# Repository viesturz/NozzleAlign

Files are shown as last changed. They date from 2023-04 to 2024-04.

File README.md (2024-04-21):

# NozzleAlign Probe
A mechanical nozzle probe to align multiple tools. And Nozzle probe offset.
Repeatable to ~0.01 mm.

| **[Ball probe](./BallProbe.md)** | **[Low profile ball proble](./LowProfileBallProbe.md)** | **[Rail probe](./RailProbe.md)** |
| --- | --- | --- |
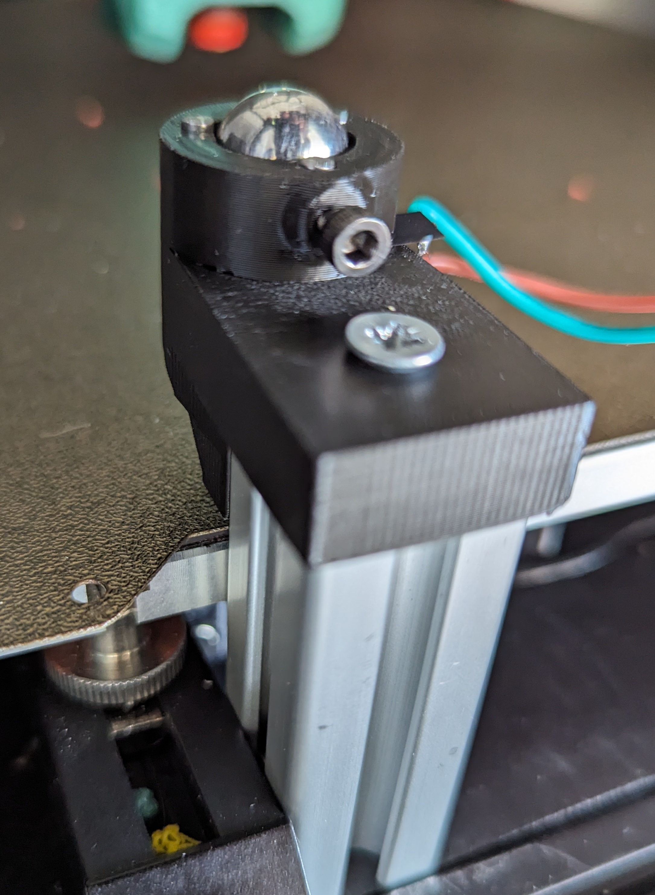
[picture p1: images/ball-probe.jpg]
Ball probe
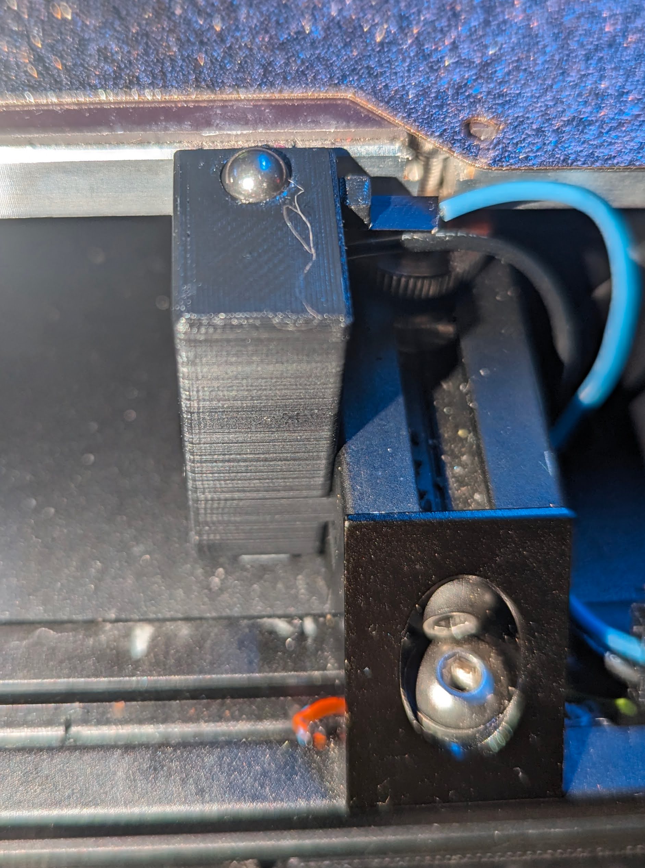
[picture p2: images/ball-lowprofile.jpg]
Low profile Ball probe
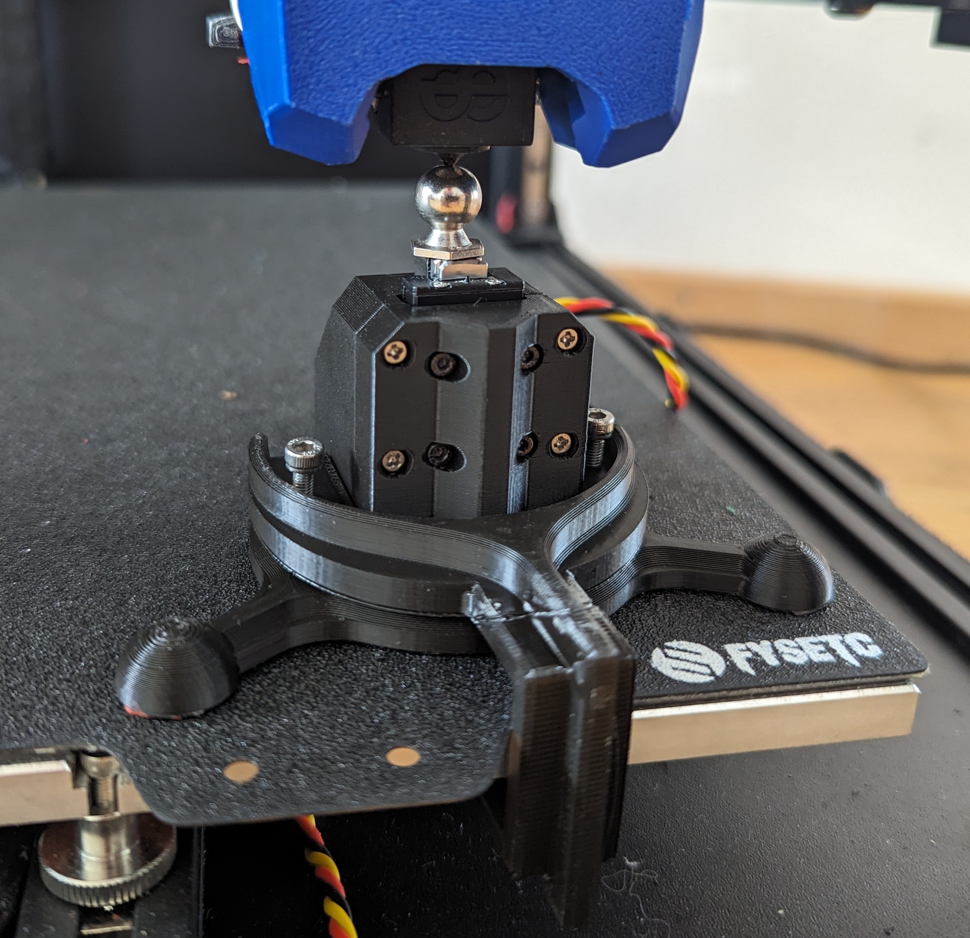
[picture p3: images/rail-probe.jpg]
Ball probe
|  |  |  |

## Klipper integration

### Installing

Install the [klipper-toolchanger](https://github.com/viesturz/klipper-toolchanger) extension.

### Configuration

See the macros folder for an example.

```
[tools_calibrate]
pin: ^!PF5
travel_speed: 20  # mms to travel sideways for XY probing
spread: 7  # mms to travel down from top for XY probing
lower_z: 1.0  # The speed (in mm/sec) to move tools down onto the probe
speed: 2  # The speed (in mm/sec) to retract between probes
lift_speed: 4  # Z Lift after probing done, should be greater than any Z variance between tools
final_lift_z: 6 
sample_retract_dist:2
samples_tolerance:0.05
samples:5
samples_result: median # median, average

# Settings for nozzle probe calibration - optional.
probe: probe # name of the nozzle probe to use

trigger_to_bottom_z: 0.25 # Offset from probe trigger to vertical motion bottoms out. 
# decrease if the nozzle is too high, increase if too low.
```

### Clean your nozzles 

The calibration accuracy is as good as your nozzles are clean. 
Clean all nozzles throughly before calibrating.

### Calibrating tool offsets

- First position the nozzle approximately above the probe - the probe will find the center on it's own within 1-2 mm.

- The first tool has all offsets to 0 and is used as a baseline for other tools. Run ```TOOL_LOCATE_SENSOR``` to calibrate nozzle location for tool 0.

- For every other tool, run ```TOOL_CALIBRATE_TOOL_OFFSET``` to measure the offset from the first tool.

All probing moves and final offsets will be printed in the console.

### Calibrating nozzle bed probe.

- Do the first two steps from above to ensure the probe is precisely under the nozzle.

- Run TOOL_CALIBRATE_PROBE_OFFSET - to measure Z offset from nozzle triggering the probe to tool's nozzle probe activating.

All probing moves and final offsets will be printed in the console.

## Troubleshooting

- **Probe triggered prior to movement**, the nozzle is not touching the probe
  - Check if the probe is triggering without touching - use a multimiter to check for continuity and if it changes when pressing down on the probe.
  - Check if the pin is configured correctly. The example configuration is for active low with a pullup. Depending how you have wired it, you might need remove the **^!** for active-high.
- **Probe triggered prior to movement**, the nozzle is touching the probe, could have probed a few times already
  - Likely the initial position was too far off-center. Try to position it more accurately.
  - The probe is lowered too much and/or not enough sideways - tweak ```lower_z``` and ```spread```

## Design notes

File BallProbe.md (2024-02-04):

# Ball probe

A rigidly mountable nozzle calibration probe using bearing balls. Accuracy is no worse than the linear rail probe.

Two versions for 12.7mm and 10mm balls available.

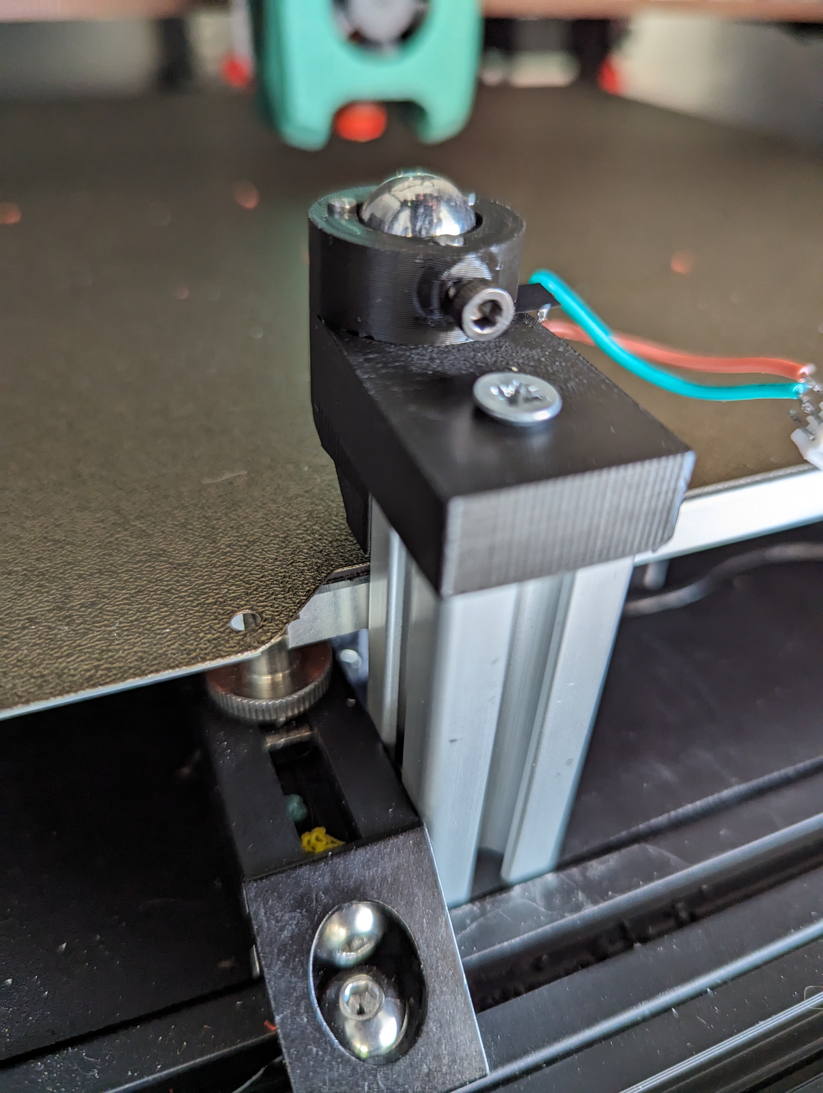
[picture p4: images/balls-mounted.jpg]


## BOM
* 2x steel ball, 10.0 or 12.7 mm
* a ~20mm piece of 0.1mmx6mm springsteel, ripped mine out of 1m tape measure.
* 3x 9mm x 3mm steel rod
* 1x 6mm x 3mm screw for adjustment
* 60mm 2020 extrusion for mounting.
* mounting hardware to attach it to your printer.
* some ~1000 grit sandpaper.

## Assembly

- Clean up the springsteel insertion slot, it should go through but have some resistance. If too loose can fix up with glue later.
- Cut the springsteel to size, it will be slightly curved, polish the outside of the curve - it will be touching the bottom ball
- Solder one wire to the polished side of springsteel
- Strip about 1cm of the other wire, fold onto itslef
- Insert the folded wire in the side hole, push down the first ball - the wire should be press fixed in place.
- Insert the springsteel into it's slot, curving up, it should clear the bottom ball.
- Insert the rods
- Push down the second ball, it should be loose between the rods and be held in by the small bumps at the top
- Make sure the top ball is moving down when pressed and rebounces back
- Tighten the adjustment screw to remove as much slack as possible. Some slack is fine.

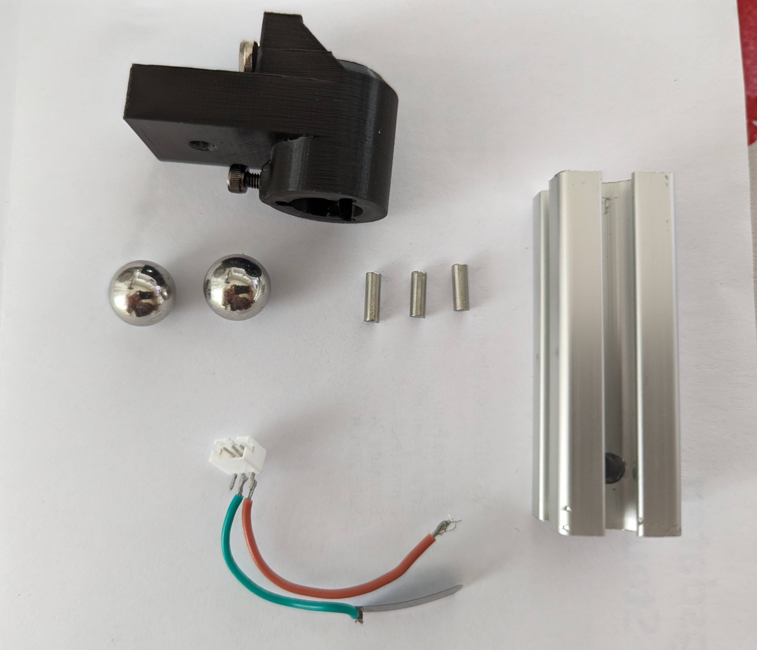
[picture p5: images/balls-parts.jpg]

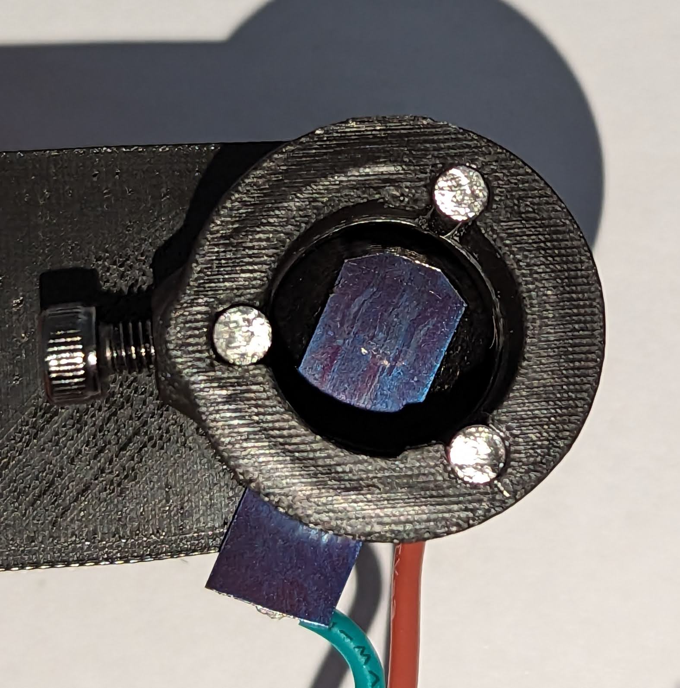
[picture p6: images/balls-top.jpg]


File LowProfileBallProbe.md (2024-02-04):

# Low profile Ball probe

A rigidly mountable nozzle calibration probe using 6mm bearing balls.

Preview

## BOM
* 2x steel ball, 6mm
* a ~15mm piece of 0.1mmx3mm springsteel, ripped mine out of 1m tape measure.
* mounting hardware to attach it to your printer.
* some ~1000 grit sandpaper.

## Assembly

- Cut the springsteel to size, it will be slightly curved, polish the outside of the curve - it will be touching the bottom ball
- Solder one wire to the polished side of springsteel
- Strip about 1cm of the other wire, fold onto itslef
- Insert the folded wire in the side hole, push down the first ball - the wire should be press fixed in place.
- Insert the springsteel into it's slot, curving up, it should clear the bottom ball.
- Make sure the top ball is moving down when pressed and rebounces back
- Add some grease on the top ball

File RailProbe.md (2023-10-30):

# Rail brobe

Uses a linar rail for the vertical motion.

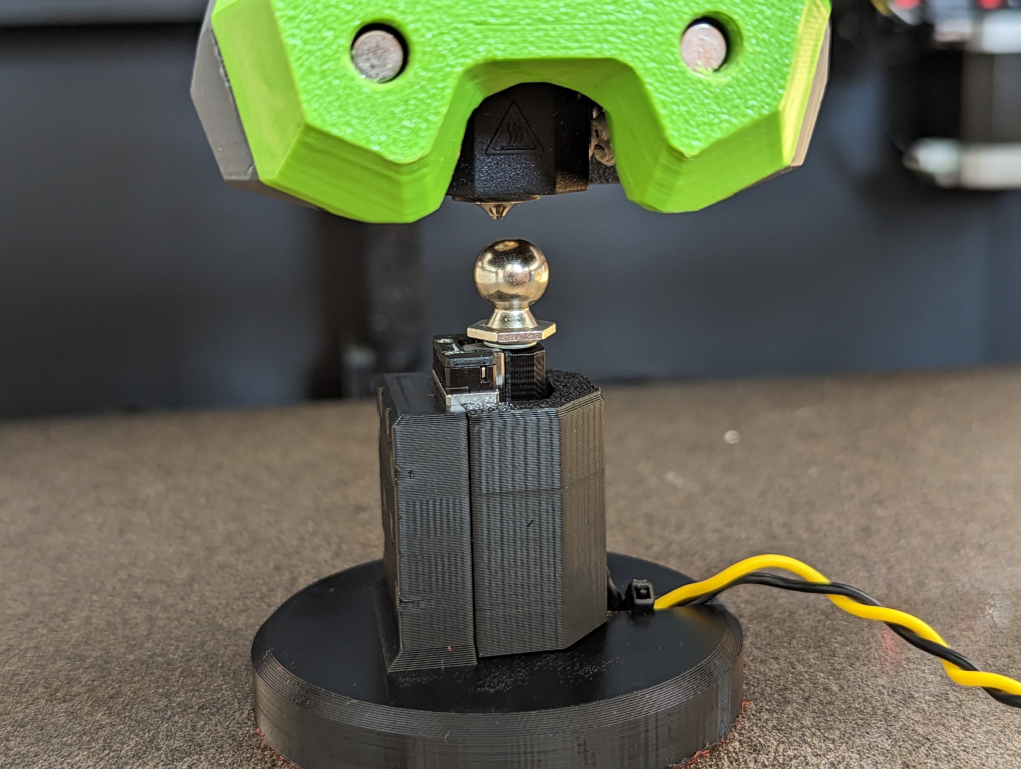
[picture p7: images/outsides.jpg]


[Video](https://www.youtube.com/watch?v=_GQEc5kIMZE)

## BOM
* MGN7h rail and carriage. Cut the rail down to 34mm.
* A threaded steel ball with m3 thread, salvaged mine from a delta printer.  There is plenty on [AliExprees](https://www.aliexpress.com/w/wholesale-steel-ball--thread.html).
* a D2F microswitch - same as Voron 0 BOM.
* 6x M2x8 bolts and nuts.
* 4x M2x12 self tapping screws to close it up.
* ~5mmx10mm self tapping countersunk screw for the base, I found a [Ikea drawer rail scew](https://www.google.com/search?q=ikea+drawer+rail+screw) in my randoms bin.
* 2x M2 heat set inserts, or mod for nuts

## Assembly

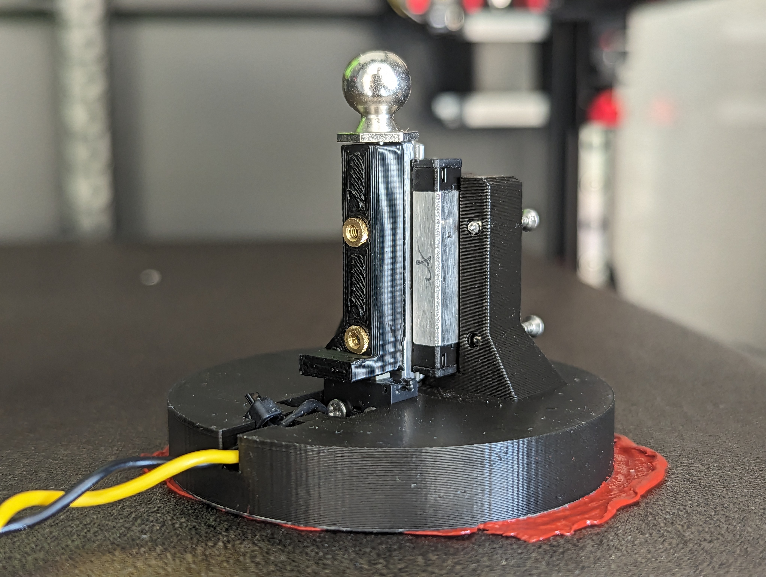
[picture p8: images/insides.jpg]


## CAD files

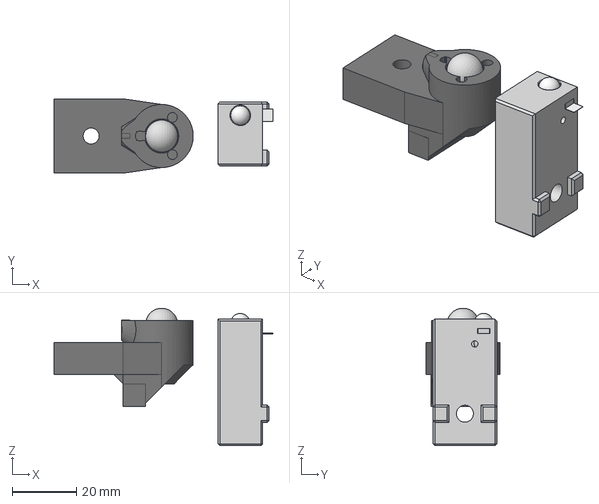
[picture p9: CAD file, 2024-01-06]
CAD/Ball probes.step
68.4 x 23.2 x 42.9 mm
NozzleAlign
Calibration pin 6mm dual ball

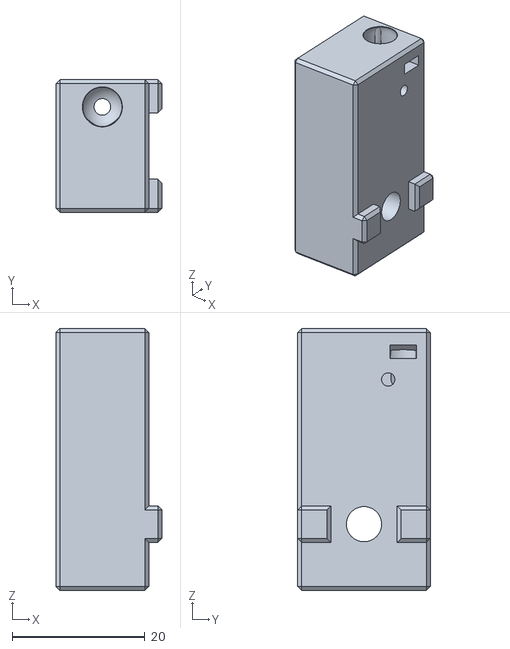
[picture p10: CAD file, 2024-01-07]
STL/Balls/Base-6mm.stl
16.0 x 20.0 x 39.5

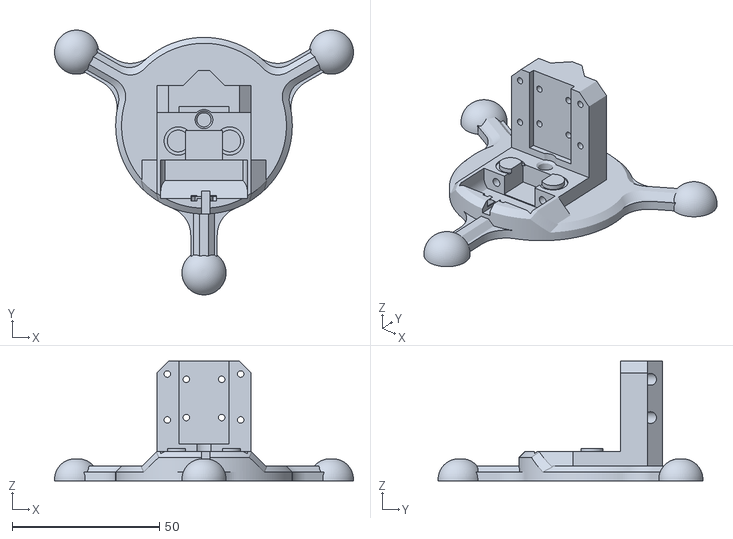
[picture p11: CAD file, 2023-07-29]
STL/OptoTap/Base.stl
101.6 x 90.0 x 40.7

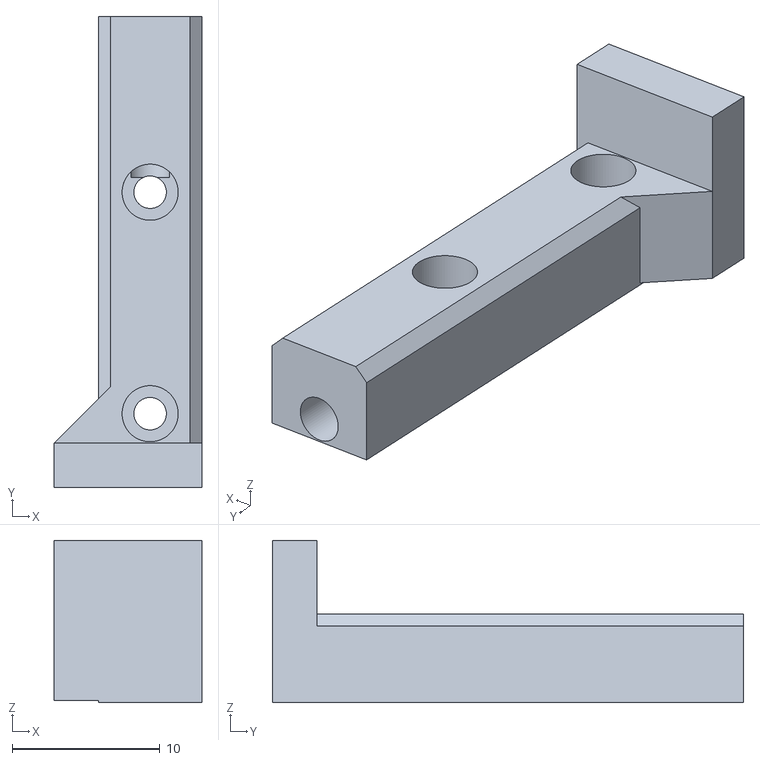
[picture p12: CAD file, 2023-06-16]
STL/Switch/Rail.stl
10.0 x 31.9 x 11.0

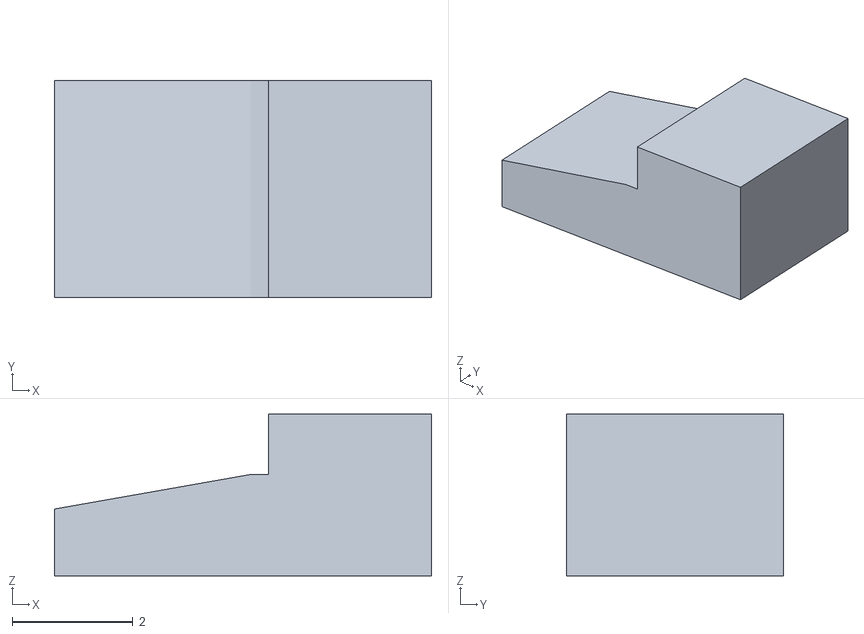
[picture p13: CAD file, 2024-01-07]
STL/Balls/Wedge-6mm.stl
6.24 x 3.60 x 2.68

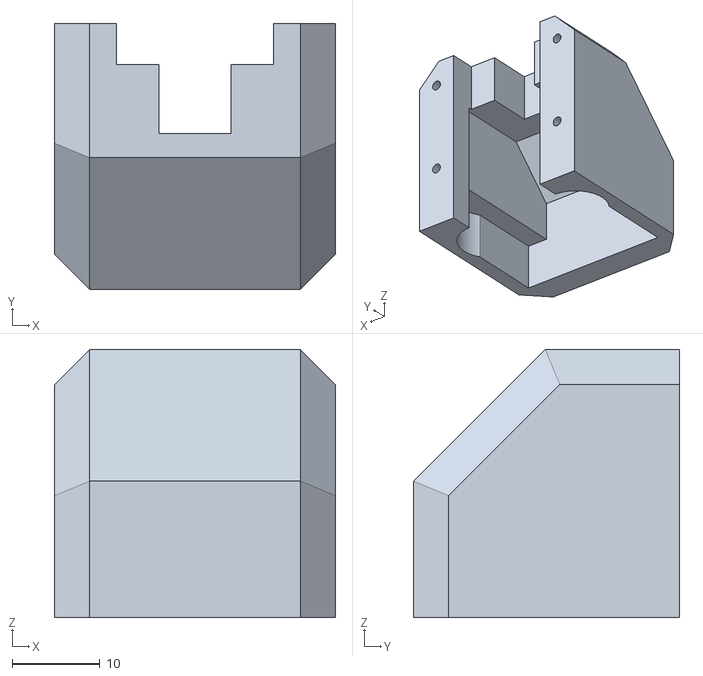
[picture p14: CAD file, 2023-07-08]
STL/OptoTap/Hat.stl
32.0 x 30.3 x 30.5

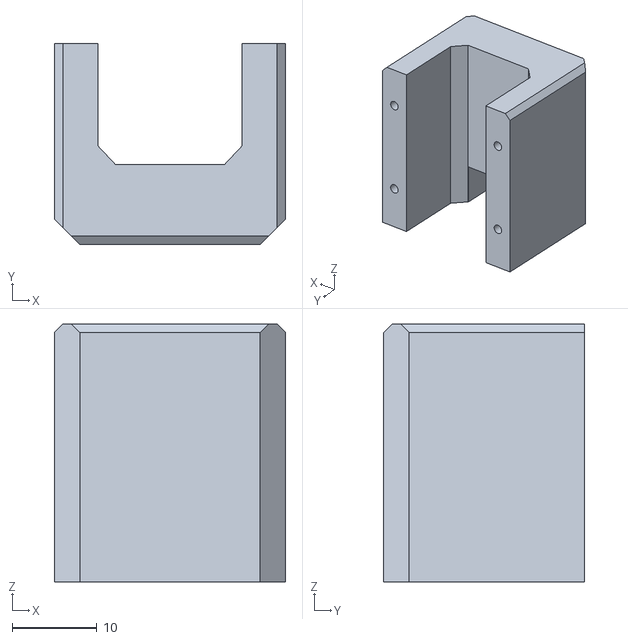
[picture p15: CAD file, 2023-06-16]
STL/Switch/Shell.stl
27.3 x 23.8 x 30.5

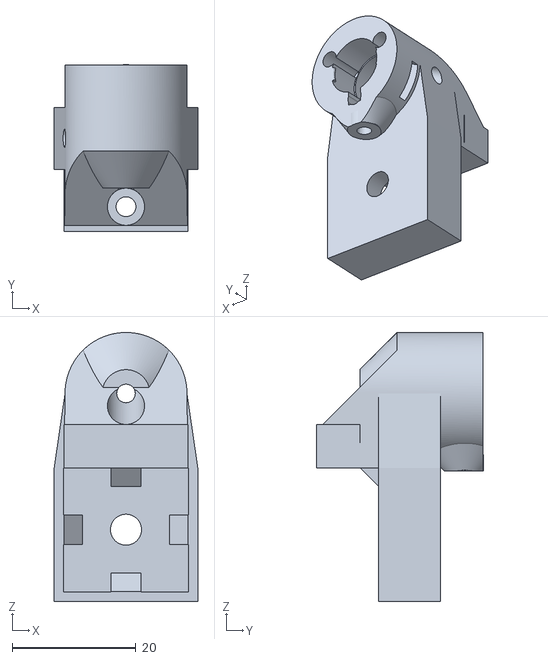
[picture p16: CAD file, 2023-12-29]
STL/Balls/Base-10mm.stl
23.2 x 27.0 x 43.4

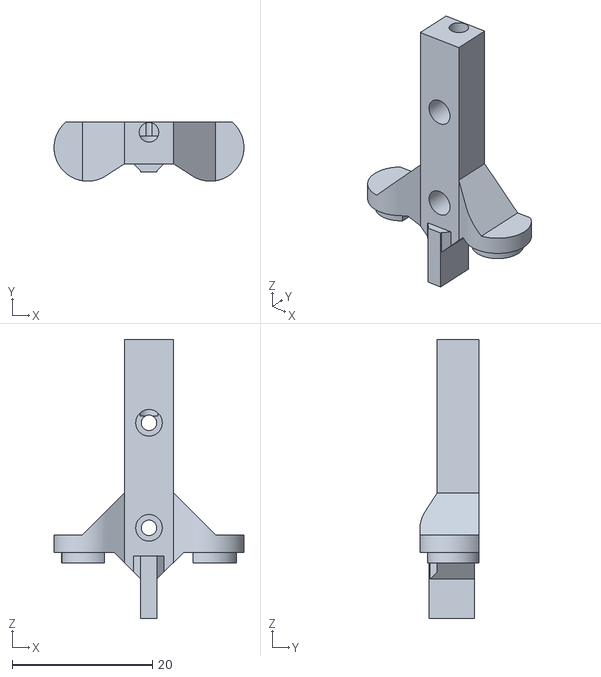
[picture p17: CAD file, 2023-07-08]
STL/OptoTap/RailAttachment.stl
27.1 x 8.49 x 39.9

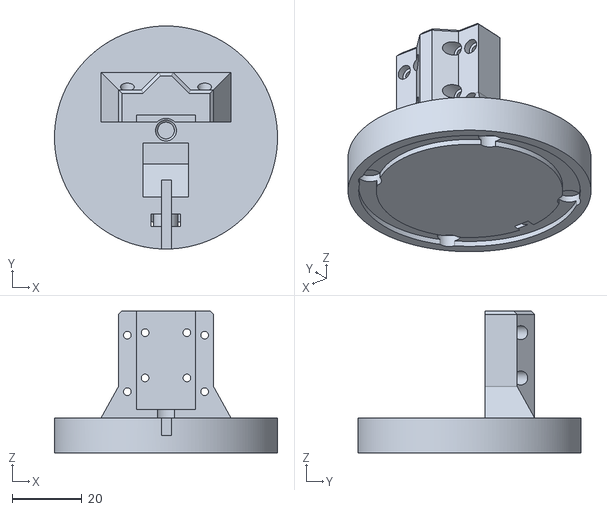
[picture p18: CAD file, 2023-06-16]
STL/Switch/Base.stl
64.0 x 64.0 x 40.7

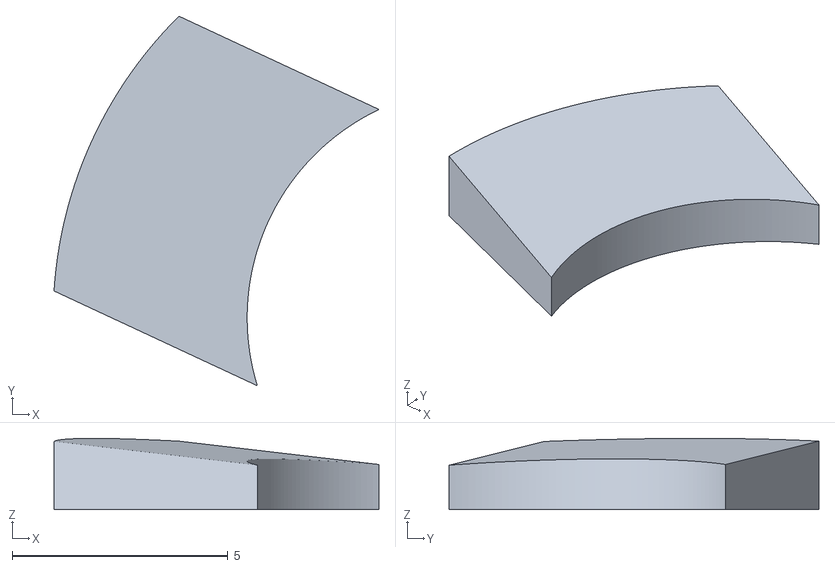
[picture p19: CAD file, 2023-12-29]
STL/Balls/Wedge.stl
7.54 x 8.57 x 1.65

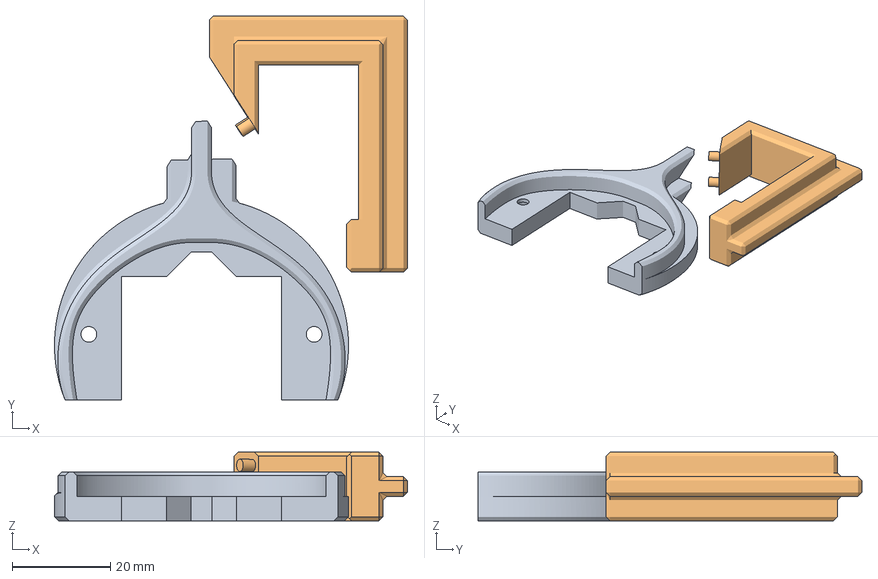
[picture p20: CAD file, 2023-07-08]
STL/OptoTap/Clamp.3mf
72.0 x 78.3 x 14.0 mm
Clamp.stl x 2

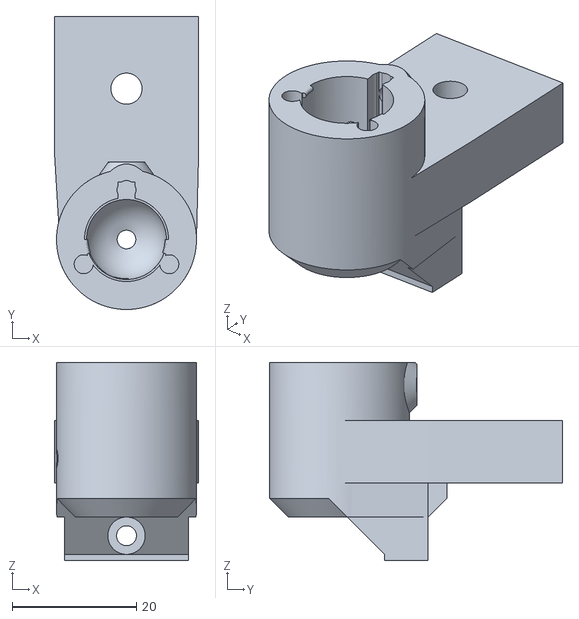
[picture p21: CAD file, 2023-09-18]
STL/Balls/Base-12.7mm.stl
23.2 x 47.1 x 31.9

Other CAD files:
CAD/Ball probes.f3z
CAD/Calibration pin.f3d
CAD/OptoTap.f3d
STL/OptoTap/Clamp.stl

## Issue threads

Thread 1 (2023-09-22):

Error on Klipper startup

joseph-greiner, 2023-09-22:
Tried to install this, received the following error:
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

I tried commenting out [probe] sections in my config, but the same error appears.
I tried adding the other module files under the tap changer repo.

Here is the klipper log file if it helps. I think this would be very useful on my printer, especially after seeing the video about it.
Do I need to be on a specific branch of Klipper for it to work?

[klippy.log](https://github.com/viesturz/NozzleAlign/files/12704844/klippy.log)

viesturz, 2023-09-23:
Hi, nozzle align relies on a bed probe being present in your config.
It's used for the probe offset calculation.
It looks like the issue is that probe is defined after [tools_calibrate] in your config. Moving it up should fix.
I'm updating the code so that it does not matter.

viesturz, 2023-09-23:
Updated to make the [probe] access entirely optional, only when you call TOOL_CALIBRATE_PROBE_OFFSET

joseph-greiner, 2023-09-23:
Thank you, I usually put my [include] at the top of the file (old habits). I re-downloaded and tried this, I got the same error. I moved [include calibrate-offsets.cfg] to below the [probe] section and I no longer get startup errors.

Closed 2023-09-23.

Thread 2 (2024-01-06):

CAD files for the ball probe are missing

mbrunner77, 2024-01-06:
Would you share the CAD file for the ball probe? I would like to mix the LDO nozzle probe with your ball probe.
thx

viesturz, 2024-01-06:
Sure, added. There is a WIP low prifile 6mm version as well. Very untested.

Closed 2024-01-06.

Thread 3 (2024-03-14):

Error during homing move

Dan3dp, 2024-03-14:
Hi,

I have an IDEX Klipper printer where I try to implement your script.

After tapping the sensor from above, T0 lower itself a little, position himself sideway and comes this error in the console :

_Error during homing move: Move out of range: 359.000 8.999 47.167 [0.000]

Error during homing move: Move out of range: 359.000 8.999 47.167 [0.000]

Probe made contact at 216.000000,8.999313,48.166563_

Why homing? My expectation was that it starts tapping the sensor from the side.

Thanks in advance for reply

viesturz, 2024-04-20:
For Klipper, homing moves are any moves that stop when a sensor is
triggered.

So all the moves that try to tap on the sensor are homing moves.

The messages below are not sufficient to understand what's going on. If you
can attach a copy of klippy.log right after this happens.

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

easycorexy, 2024-04-21:
Hi thanks for your reply,
[klippy.log](https://github.com/viesturz/NozzleAlign/files/15051081/klippy.log)

i've attached the Klippy.log

viesturz, 2024-04-21:
Ahh, you have idex and the movement limits change depending on the selected
toolehad. Let me fix that...

On Sun, Apr 21, 2024 at 10:06 AM easycorexy ***@***.***>
wrote:

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

viesturz, 2024-04-21:
There,
https://github.com/viesturz/klipper-toolchanger/commit/d7159020019fdb6f207aeb381f20fa44f68a11f0

Let me know if it fixes your issue.

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

viesturz, 2024-04-21:
Also I removed the extras folder from this repo, it's out of date and maintaining two is a pain.
Please use the version in klipper-toolchanger repo.

easycorexy, 2024-04-21:
So, yes, the initial issue is gone.
But now something else is happening:

20:42
Probe triggered prior to movement
20:42
Probe triggered prior to movement
20:42
Probe made contact at 221.500616,8.999313,47.691094

The probing on Z axis is done, than the printhead goes sideways and make the lateral probing, in the moment the probe is triggered comes this error 'Probe triggered prior to movement'. Which is not true, the probe is triggered exactly when it supposed to be triggered.

I've played with spread an z values in the config file, but the behaviour remained the same.

[klippy.log](https://github.com/viesturz/NozzleAlign/files/15053124/klippy.log)

viesturz, 2024-04-23:
Each probing is repeated multiple times, with a small retraction movement
to reset the sensor.
It seems that your sensor is not resetting.

Try increasing the sample_retract_dist.
Or increasing lower_z if the horizontal angle is too shallow.
Or maybe the sensor just gets stuck when approached from the side.

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

easycorexy, 2024-04-26:
Hi,
I think is something else.
I've added a 'gcode_button' to see the sensor status during the probing.
The sensor do what it supposed to do.

I've made several adjustments to 'sample_retract_dist' and  'lower_z' but it didn't help....

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

[https://drive.google.com/file/d/17hXl2S6gFP7CV39KYK6UG3xAuHg0AJ7v/view?usp=drive_link](url)

seacred, 2024-06-16:
i got the same Issue.
the sensor seems to trigger to much to be reliable.
Is there a fix?

viesturz, 2024-06-16:
Which sensor are you using?

On Sun, Jun 16, 2024 at 1:50 PM Julian Strohm ***@***.***>
wrote:

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

a480615, 2024-06-18:
Hello, I have encountered the same issue. I have tried adjusting the spread, lower_z, and sample_retract_dist parameters, but no matter how I adjust them, the same problem persists. The first downward probe triggers and obtains parameters correctly, but during the second horizontal probe, the error occurs as soon as it triggers.
[klippy (8).log](https://github.com/user-attachments/files/15891138/klippy.8.log)
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

viesturz, 2024-06-19:
A video fo the movement when this happens would be really helpful.

I can image one of the following happening:
* the nozzle fails to move away sufficently for the probe to reset
* the nozzle moves away, but the probe is mechanically stuck triggered
* there is some issue with the code

seacred, 2024-06-21:
Sorry for not updating here.
For me this PR fixed it:
https://github.com/viesturz/klipper-toolchanger/pull/23#event-13220176480
and is already commited. @a480615 try updating and check again if this error persist. If so, try to make sure there is no mechanical issue. Since i use Nudge as a probe, there are some things you need to get as accurate as possible to make the probe consistent

a480615, 2024-06-21:
> Sorry for not updating here. For me this PR fixed it: [viesturz/klipper-toolchanger#23 (comment)](https://github.com/viesturz/klipper-toolchanger/pull/23#event-13220176480) and it's already commited. @a480615 @Dan3dp try updating and check again if this error persist. If so, try to make sure there is no mechanical issue. Since i use Nudge as a probe, there are some things you need to get as accurate as possible to make the probe consistent

Thank you for your response. After updating the plugin, it is now working properly.

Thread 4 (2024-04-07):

Unsolved error during toolhead.manual_move

fraserw, 2024-04-07:
I am trying to add a new function to extend probe calibration for the BLTouch.

I have defined a minimal test function called HACK that simply adjusts the z-height based on a previously determined location vector. This returns "!! Internal error..." and I cannot see why:

   def cmd_HACK(self, gcmd):
        toolhead = self.printer.lookup_object('toolhead')
        start_pos = toolhead.get_position()
        location = [99., 218. ,58.]
        self.gcode.respond_info("%.3f %.3f %.3f"%(location[0],location[1],location[2]))

        new_z = location[2] + 10.0
        toolhead.manual_move([None, None, new_z], self.lift_speed)

I am sure I am missing something obvious.

viesturz, 2024-04-10:
You should be able to see the full error in klippy.log . Start from the
bottom and scroll up until you see a python stack trace printed

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

fraserw, 2024-04-28:
Thanks. I wasn't aware of the log. That revealed my issues.

fraserw, 2024-04-28:
Solved!

Closed 2024-04-28.

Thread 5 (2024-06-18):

1

a480615, 2024-06-18:
1

viesturz, 2024-06-19:
Just to reply to the original content.
Looks possible, the treads might interfere significantly however.

A round head revet would work better: https://www.google.com/search?q=rivet%20round%20head
There are def advantages to this, making a test....

a480615, 2024-06-19:
> 只是为了回复原始内容。看起来有可能，但胎面可能会受到显着干扰。
>
> 圆头 revet 会更好： https://www.google.com/search?q=rivet%20round%20head 这样做有明显的优势，做一个测试......

> Just to reply to the original content. Looks possible, the treads might interfere significantly however.
>
> A round head revet would work better: https://www.google.com/search?q=rivet%20round%20head There are def advantages to this, making a test....

Okay, thank you for your reply. Once I can successfully use NozzleAlign, I will proceed to test it. For this purpose, I've modeled a solution based on your design, involving a screw or rivet. The parts list roughly consists of two F695 bearings, one rivet, and one micro switch.
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
https://github.com/viesturz/NozzleAlign/assets/166965276/ed8d150a-d50c-48ef-ae30-2b4d2bc69e07

a480615, 2024-06-19:
> Just to reply to the original content. Looks possible, the treads might interfere significantly however.
>
> A round head revet would work better: https://www.google.com/search?q=rivet%20round%20head There are def advantages to this, making a test....

I'm sorry, but currently I've only assembled the relevant hardware and cannot conduct actual usability tests. I believe you might have seen my response in another thread. Like others, I encountered an issue during the NozzleAlign center-finding process where the first X-axis movement triggering the limit switch resulted in an error.

My friends and I have discussed this issue extensively. Throughout this process, I tried adjusting parameters according to your troubleshooting suggestions, as well as switching the wiring of the micro switch between NC and NO, but none of these methods resolved the issue.

Finally, my friend informed me that when researching this issue, they saw that the boss of the Voron team seemed to have encountered the same issue as me (my machine's structure is similar to the hybrid CoreXY-Idex being developed by Voron). Perhaps it's a compatibility issue with this unique motion structure?

After tinkering with it all night, I've decided to temporarily abandon this approach and wait for good news from you or the Voron team. I won't give up on using this solution, but my expertise lies only in 3D modeling; I'm not proficient with coding, so I'll have to pause and wait.

It's also for the reasons mentioned above that I've closed the original thread. It's too reckless to give such casual suggestions before testing their usability.

Here's a video of my machine in action. It just needs your NozzleAlign to work perfectly:

https://github.com/viesturz/NozzleAlign/assets/166965276/06229119-1c1b-4c0c-a1a2-139ed9411811

Closed 2024-06-20.

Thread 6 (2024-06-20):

Executing the "TOOL_CALIBRATE_PROBE_OFFSET" command results in an error and crash, with the message: Internal error on command: "TOOL_CALIBRATE_PROBE_OFFSET".

a480615, 2024-06-20:
Hello, I encountered a new problem. After yesterday's update, my IDEX machine can finally run NozzleAlign. The TOOL_LOCATE_SENSOR and TOOL_CALIBRATE_TOOL_OFFSET commands can be called and produce accurate data. However, when executing the "TOOL_CALIBRATE_PROBE_OFFSET" command, the machine crashes after the print head presses down a few times. I cannot determine the cause of this issue. I have tried changing the probe type in the configuration file, but it did not help. Attached are the screenshot and log file, as well as my configuration.
[klippy (2).log](https://github.com/user-attachments/files/15920991/klippy.2.log)
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

a480615, 2024-06-20:
I'm sorry, I think I found the cause of the issue. It was because I commented out some macros in your example file. I thought those macros were related to the tool changing function, and since I'm using an IDEX machine that doesn't use the tool changing feature, I commented them out. Now that I have activated all of them, the NozzleAlign TOOL_LOCATE_SENSOR, TOOL_CALIBRATE_TOOL_OFFSET, and TOOL_CALIBRATE_PROBE_OFFSET commands are all working properly.
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

Closed 2024-06-20.

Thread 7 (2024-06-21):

Why is my Z-axis offset calibration always consistently off by 1mm?

a480615, 2024-06-21:
Why is my Z-axis offset calibration always consistently off by 1mm? I've tried adjusting the trigger_to_bottom_z value, but whether I raise it or lower it, it has no effect. After every calibration, the nozzle height is consistently 1mm lower than the set value. What parameter should I adjust for this offset? Is it the GCODE_OFFSET?

Closed 2024-06-23.

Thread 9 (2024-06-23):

Does NozzleAlign still seem incompatible with IDEX?

a480615, 2024-06-23:
After the update a few days ago, IDEX machines could indeed utilize all NozzleAlign functions properly. However, today, while using NozzleAlign to calibrate the offset value of the second nozzle, I found that no matter how I measured, the X-axis offset value of the second nozzle was always incorrect. As shown in the picture, the measurement result for the X-axis offset value is like this. After using this offset value to print the offset calibration model, I found that the Y and Z offsets were very accurate, but the X offset had a significant error. I measured the actual X offset value using a caliper, and the result was approximately 1MM+. Regardless of whether I set the NozzleAlign measured value to positive or negative, it did not match this value at all! So, I was wondering: could NozzleAlign still have compatibility issues with IDEX machines, preventing the correct measurement and application of the second X-axis offset value?
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

https://github.com/viesturz/NozzleAlign/assets/166965276/afeebc1c-5785-4c56-b6b1-3190136cc98a

Closed 2024-06-27.

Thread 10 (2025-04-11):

z-offset probing

BiloxiGeek, 2025-04-11:
Could this device be used to measure z-offset for a single extruder and replace the paper measure method?

I'm getting Makertech ProForge 300 soon and it comes with a ball probe. I also have a Sovol SV04 and SV07+.  The ball probe for sure might get setup on the SV04 and if I'm gonna go through that I figure I might as well see if a more accurate z-offset can be measured on the SV07+.

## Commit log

2023-04-25 Add code
    [Base.stl, Calibration pin.f3d]
2023-05-05 Update calibration script
2023-06-11 Fix missing position save, add example macro.
    [calibrate-offsets.cfg]
2023-06-11 Add params for config name to automate saving the config.
    [calibrate-offsets.cfg]
2023-06-16 Update to use a switch instead of contact to the bottom screw
    [Base.stl, Calibration pin.f3d, Rail.stl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]
2023-07-08 Add optotap version
    [Base.stl, Clamp.3mf, Clamp.stl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]
2023-07-29 Update optoTap base
    [Base.stl, OptoTap.f3d]
2023-09-18 Balls aligner
    [Base.stl]
2023-09-23 More generic macro example.
    [calibrate-offsets.cfg]
2023-09-23 Lookup [probe] only when actually needed, allowing to run offset calibration even with no probe.
    [calibrate-offsets.cfg]
2023-09-23 Add ball probe instructions.
2023-09-23 More flexible config saving.
    [calibrate-offsets.cfg]
2023-09-29 Add 10m balls version
    [Base-10mm.stl, Base-12.7mm.stl]
2023-10-30 Update documentation.
    [calibrate-offsets.cfg]
2023-12-29 Add 6mm ball option.
    [Base-10mm.stl, Base-6mm.stl, Wedge.stl]
2024-01-06 Add cad file far ball probes
    [Ball probes.f3z, Ball probes.step]
2024-01-07 6mm low profile option.
    [Base-6mm.stl, Wedge-6mm.stl]
2024-02-04 Low profile probe
2024-04-21 Update installation instructions to use klipper-toolchanger repo. The fork here is no longer maintained.
